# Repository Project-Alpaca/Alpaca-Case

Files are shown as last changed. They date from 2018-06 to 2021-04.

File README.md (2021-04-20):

# Alpaca-Case

Laser cut case for Alpaca.

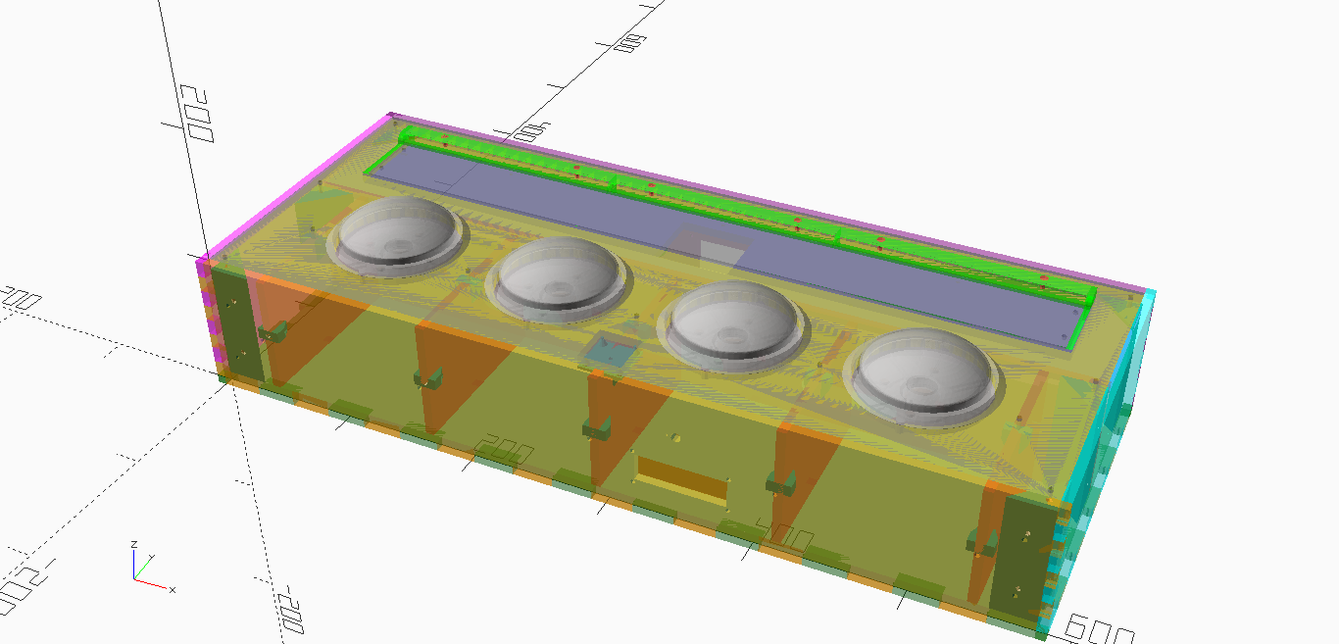
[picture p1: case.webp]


## Usage

- Don't forget to checkout all submodules by using `git submodule update --init --recursive`.
- Export the cutting (set `ENGRAVE=false`) and engraving (set `ENGRAVE=true`) profiles as DXF (via Customizer GUI or command line).
- Cut one sheet using the exported **cutting** profile.
- Engrave the same sheet using the exported **engraving** profile (beware of the alignment).
- Repeat the process using required materials until done.
- Print out all additional required parts in `models.scad` using a 3D printer.

### Customizer

The OpenSCAD Customizer is used in this project as a quick, non-invasive way to preview the design (in both 2D profile and assembled 3D model) and to simplify the build process. See the description fields in Customizer regarding to the usage of each options.

### laserscad

Make sure Python 3.9 and pipenv are installed.

After checkout or update, run

```sh
PIPENV_PIPFILE=ext/laserscad-alt/Pipfile pipenv install
```

To use laserscad support, run

```sh
PIPENV_PIPFILE=ext/laserscad-alt/Pipfile pipenv run python ext/laserscad-alt/lscad.py cut case.scad <page_width>x<page_height> -D '{"SHEET": "lscad", "PREVIEW_3D": false}'
```

(Parameters for HSI and/or LKP-Assy can be added by specifing extra parameters in the JSON object. e.g. `'{"SHEET": "lscad", "PREVIEW_3D": false, "LKP_PCB_TOTAL_LENGTH": 517, "HSI_DEPTH": 4.2}'`.)

Replace `cut` with `engrave` to generate engrave data. (WIP)

To use preview, run

```sh
PIPENV_PIPFILE=ext/laserscad-alt/Pipfile pipenv run python ext/laserscad-alt/lscad.py preview case.scad <page_width>x<page_height> -D '{"SHEET": "lscad", "PREVIEW_3D": false}'
```

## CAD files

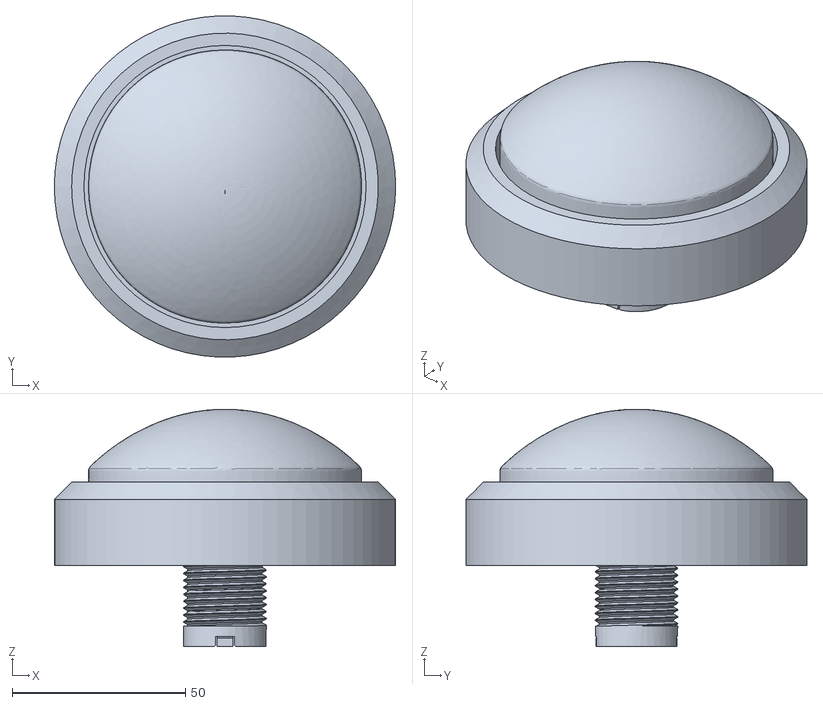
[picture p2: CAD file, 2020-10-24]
ext/adafruit-1185.stl
98.5 x 98.4 x 68.5

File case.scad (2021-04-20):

include <ext/lasercut/lasercut.scad>
include <ext/laserscad/dist/laserscad.scad>
include <footprints.scad>
use <ext/LKP-Assy/lkp-assy-ex.scad>
use <imperial.scad>
use <models.scad>

/* [Viewer Options] */
// Set this to true to get a 3D preview of the assembled controller
PREVIEW_3D = true;
_PREVIEW = $preview == undef || $preview == true ? PREVIEW_3D : false;
$fn = _PREVIEW ? undef : 48;

// Set this to true when PREVIEW_3D=false generates layer for laser engraving (mainly for position of screw holes so they can be drilled later)
ENGRAVE = false;

// box1, box2, box3 are intended to be cut from plywood, panel1 is intended to be cut from acrylic. lscad enables auto layout with laserscad. (currently requires our fork of laserscad with our custom layout script. See https://github.com/mbugert/laserscad/issues/4)
SHEET = "box1"; // [box1, box2, box3, panel1, lscad]
// Output drill layer on cut layer for direct cutting or engrave (eng) layer so that they can be drilled later.
DRILL_AS = "cut"; // [eng, cut]

// Size of panel sheet and box sheets (for reference only)
SHEET_PANEL = [in(24), in(18)];
SHEET_BOX = [in(24), in(16)];

/* [Preview Visibility] */
// Sets visibility of objects in preview

// Front
PREVIEW_FRONT_WALL = true;
// Back
PREVIEW_BACK_WALL = true;
// Left
PREVIEW_LEFT_WALL = true;
// Right
PREVIEW_RIGHT_WALL = true;
// Top cover
PREVIEW_TOP_COVER = true;
// Top panel
PREVIEW_TOP_PANEL = true;
// Bottom
PREVIEW_BOTTOM = true;
// Mounting brackets
PREVIEW_MOUNTING = true;
// Supports
PREVIEW_SUPPORT = true;
// LKP platform
PREVIEW_LKP_PLATFORM = true;
// LKP
PREVIEW_LKP = true;
// Button preview
PREVIEW_BUTTONS = true;

/* [Hidden] */

// Dimension settings

// Thickness of sheets
BOX_THICKNESS = in(1/4);
PANEL_THICKNESS = mil(80);

// Size of the inner box (without accounting controller panel)
BOX_SIZE = [580, 225, 95];
PANEL_SIZE_REF = [635, 225];

// Size of the outer edge
OUTER_SIZE = [
    BOX_SIZE.x + 2*BOX_THICKNESS,
    BOX_SIZE.y + 2*BOX_THICKNESS,
    // no tabs for z axis
    BOX_SIZE.z + BOX_THICKNESS
];
// Size of the inner box (minus controller panel thickness)
INNER_SIZE = [
    BOX_SIZE.x,
    BOX_SIZE.y,
    BOX_SIZE.z - BOX_THICKNESS - PANEL_THICKNESS
];

FINGER_COUNT = [10, 5, 4];

BUTTON_DIST = 125;
BUTTON_OFFSET_REF = [130, 75];
BUTTON_OFFSET = [
    BUTTON_OFFSET_REF.x - ((PANEL_SIZE_REF.x - BOX_SIZE.x) / 2),
    BUTTON_OFFSET_REF.y - ((PANEL_SIZE_REF.y - BOX_SIZE.y) / 2),
];
BUTTON_R_WITH_NOTCH = (ARCADE_BUTTON_100MM_HOLE_DIA + ARCADE_BUTTON_100MM_NOTCH_DIA) / 2;
SLIDER_SIZE_REF = [500, 40];
// Bottom of the slider, starts from the center of the buttons.
SLIDER_BOTTOM_Y = 75;
// Center of the slider, starts from the center of the buttons.
SLIDER_OFFSET_REF = [1.5*BUTTON_DIST, SLIDER_BOTTOM_Y + SLIDER_SIZE_REF.y/2];
// Button sits at zero. Therefore teh gap between slider and button (hole) would be (the slider bottom offset - the button radius with notch)
SLIDER_BUTTON_GAP_CENTER = SLIDER_BOTTOM_Y - ((SLIDER_BOTTOM_Y - BUTTON_R_WITH_NOTCH) / 2) + BUTTON_OFFSET.y;
BUTTON_OFFSET_BACKOFF = BUTTON_R_WITH_NOTCH + BUTTON_OFFSET.y + BOX_THICKNESS / 2 + 3;
LKP_PLATFORM_OFFSET = [0, BUTTON_OFFSET_BACKOFF + BOX_THICKNESS / 2];
SUPPORT_CORNER_OFFSET_Y = BUTTON_OFFSET_BACKOFF - BOX_THICKNESS/2;

// Center of the slider, starts from the bottom left of slider platform.
SLIDER_OFFSET_PLATFORM = SLIDER_OFFSET_REF + BUTTON_OFFSET - LKP_PLATFORM_OFFSET;

//SOFTPOT_WIDTH = 20;
//SOFTPOT_DEADZONE_WIDTH = 6;

// Internal use only. Do not change.

EPSILON = .1;

// Automatically generated dimension parameters
_box_side_fb_idim = [BOX_SIZE.x, BOX_SIZE.z];
_box_side_lr_idim = [BOX_SIZE.z, BOX_SIZE.y];
_box_tb_idim = [BOX_SIZE.x, BOX_SIZE.y];
_box_side_f_idim = _box_side_fb_idim;
_box_side_b_idim = _box_side_fb_idim;
_box_bottom_idim = _box_tb_idim;
_box_top_idim = _box_tb_idim;
_box_support_v_button_idim = [INNER_SIZE.z, BUTTON_OFFSET_BACKOFF - BOX_THICKNESS / 2];
_box_support_h_idim = [INNER_SIZE.x, INNER_SIZE.z];
_box_lkp_platform_idim = [INNER_SIZE.x, INNER_SIZE.y - LKP_PLATFORM_OFFSET.y];
_box_support_v_slider_idim = [BOX_SIZE.z-PANEL_THICKNESS+lkp_get_assy_zoffset()-BOX_THICKNESS, _box_lkp_platform_idim.y];


function account_for_fingers(dim, tb, lr) = [
    dim.x + BOX_THICKNESS * lr,
    dim.y + BOX_THICKNESS * tb,
];

_box_side_fb_xdim = account_for_fingers(_box_side_fb_idim, 1, 2);
_box_side_lr_xdim = account_for_fingers(_box_side_lr_idim, 2, 1);
_box_top_xdim = _box_top_idim;
_box_bottom_xdim = account_for_fingers(_box_bottom_idim, 2, 2);

// 1 group of fingers on the bottom
_box_support_h_xdim = account_for_fingers(_box_support_h_idim, 1, 0);
// 1 group of fingers on the vertical support and 1 group on the bottom
_box_support_v_button_xdim = account_for_fingers(_box_support_v_button_idim, 1, 1);
// 1 group of fingers on the vertical support and 1 group on the bottom
_box_support_v_slider_xdim = account_for_fingers(_box_support_v_slider_idim, 1, 1);
_box_lkp_platform_xdim = _box_lkp_platform_idim;

// Accounting for the thickness for lasercut boards
function as_lcb_center(pos) = pos - BOX_THICKNESS/2;

// Button gap center (-1: Before first button, 0: Gap center between the first and the second button)
function button_gap_center(pos) = BUTTON_DIST * (0.5+pos);

module extrude_box() {
    linear_extrude(BOX_THICKNESS) children();
}

module extrude_panel() {
    linear_extrude(PANEL_THICKNESS) children();
}

// Align box object's outer perimeter to the axis origin
module box_align_to_op(fingered_x=true, fingered_y=true) {
    translate([
        fingered_x ? BOX_THICKNESS : 0,
        fingered_y ? BOX_THICKNESS : 0,
    ]) children();
}

function support_index(i) = BUTTON_OFFSET.x+as_lcb_center(button_gap_center(i-1)+BOX_THICKNESS/2);

module copy_to_support_center(x_only=false) {
    for (i=[0:4]) {
        translate([support_index(i), 0, x_only ? 0 : BOX_THICKNESS]) children();
    }
}

module copy_to_support_center_no_oled(x_only=false) {
    for (i=[0, 1, 3, 4]) {
        translate([support_index(i), 0, x_only ? 0 : BOX_THICKNESS]) children();
    }
}

module move_to_support_center_oled(x_only=false) {
    translate([support_index(2), 0, x_only ? 0 : BOX_THICKNESS]) children();
}

module copy_to_slider_support_center(x_only=false) {
    for (i=[0:3]) {
        translate([support_index(i+0.5), 0, x_only ? 0 : BOX_THICKNESS]) children();
    }
}

module extrude_box_cutout() {
    translate([0, 0, -EPSILON])
    linear_extrude(BOX_THICKNESS+2*EPSILON)
        children();
}

module extrude_panel_cutout() {
    translate([0, 0, -EPSILON])
    linear_extrude(PANEL_THICKNESS+2*EPSILON)
        children();
}

module from_button_origin() {
    translate(BUTTON_OFFSET) children();
}

module corner_screw_holes(x, y) {
    //translate([0, 0, 0]) circle(d=3.2);
    translate([x, 0, 0]) circle(d=3.2);
    translate([0, y, 0]) circle(d=3.2);
}

// Wrappers
module support_holder_w(profile="3d", align_y="c") {
    support_holder(thickness=BOX_THICKNESS, profile=profile, align_y=align_y);
}

module corner_support_w(profile="3d") {
    corner_support(inner_height=INNER_SIZE.z, profile=profile);
}

module oled_holder_w(profile="3d-assy") {
    oled_holder(thickness=BOX_THICKNESS, profile=profile);
}
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

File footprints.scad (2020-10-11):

// Various footprints and their constants

include <imperial.scad>

/* [Hidden] */

// Constants. Do not edit.

// https://www.adafruit.com/product/1185#technical-details
ARCADE_BUTTON_100MM_DIA = 100;
ARCADE_BUTTON_100MM_HOLE_DIA = 88; // on drawing: 87.8
ARCADE_BUTTON_100MM_NOTCH_DIA = 6.2; // on drawing: 6.0

module footprint_arcade_button_100mm() {
    union() {
        _r = ARCADE_BUTTON_100MM_HOLE_DIA / 2;
        // main hole
        circle(d=ARCADE_BUTTON_100MM_HOLE_DIA);
        // notch
        translate([0, _r, 0]) {
            circle(d=ARCADE_BUTTON_100MM_NOTCH_DIA);
        }
        translate([0, -_r, 0]) {
            circle(d=ARCADE_BUTTON_100MM_NOTCH_DIA);
        }
    }
}

//module footprint_1602() {
//    square([80, 36], true);
//}

// Drill: invert=true, tail_cut=false
// Tail cut (difference): invert=true, holes=false
// TODO account for tail when positioning tail cut.
module footprint_softpot_mount(softpot_length=500, softpot_width=20, padding=20, invert=false, holes=true, tail_cut=true) {
    module _screw_holes() {
        offset_x = half_l + screw_hole_offset_from_pot;
        offset_y = half_w + screw_hole_offset_from_pot;
        translate([-offset_x, -offset_y]) circle(d=3.2);
        translate([offset_x, -offset_y]) circle(d=3.2);
        translate([-offset_x, offset_y]) circle(d=3.2);
        translate([offset_x, offset_y]) circle(d=3.2);
    }

    module _tail_cut() {
        offset_x = half_l + 5;
        translate([offset_x, 0]) square([3, 11], center=true);
    }

    screw_hole_offset_from_pot = padding / 4;
    half_l = softpot_length / 2;
    half_w = softpot_width / 2;

    if (!invert) {
        difference() {
            square([softpot_length+padding, softpot_width+padding], center=true);
            if (holes) _screw_holes();
            if (tail_cut) _tail_cut();
        }
    } else {
        %square([softpot_length+padding, softpot_width+padding], center=true);
        if (holes) _screw_holes();
        if (tail_cut) _tail_cut();
    }
    %square([softpot_length, softpot_width], center=true);
}

module footprint_1602() {
    %square([80, 36], center=true);
    square([73, 26], center=true);
}

module footprint_1602_eng() {
    %square([80, 36], center=true);
    translate([-80/2, -36/2, 0]) {
        translate([2.5, 2.5, 0]) circle(d=3.2);
        translate([80-2.5, 36-2.5, 0]) circle(d=3.2);
        translate([80-2.5, 2.5, 0]) circle(d=3.2);
        translate([2.5, 36-2.5, 0]) circle(d=3.2);
    }
}

module footprint_control() {
    %square([70, 30], center=true);
    square([63, 20], center=true);
}

module footprint_control_eng() {
    %square([70, 30], center=true);
    translate([-70/2, -30/2, 0]) {
        translate([2.5, 2.5]) circle(d=3.2);
        translate([70-2.5, 30-2.5, 0]) circle(d=3.2);
        translate([70-2.5, 2.5, 0]) circle(d=3.2);
        translate([2.5, 30-2.5, 0]) circle(d=3.2);
    }
}

module footprint_re() {
    %square([26, 19], center=true);
    translate([-3, 1.5]) {
        circle(d=7);
        translate([-6, 0]) {
            square([1, 2], center=true);
        }
    }
}

module footprint_re_eng() {
    %square([26, 19], center=true);
    //translate([-3, 1.5]) circle(d=7);
    translate([-26/2, -19/2, 0]) {
        translate([4.5, 2.5]) circle(d=3.2);
        translate([26-4.5, 2.5]) circle(d=3.2);
    }
}
module footprint_adafruit_908_ref() {
    translate([-14, 0]) hull() {
        circle(d=12);
        translate([28, 0]) circle(d=12);
    }
}

module footprint_adafruit_908() {
    %footprint_adafruit_908_ref();
    square([14.5, 7], center=true);
}

module footprint_adafruit_908_eng() {
    %footprint_adafruit_908_ref();
    translate([15, 0]) circle(d=in(7/64));
    translate([-15, 0]) circle(d=in(7/64));
}

module footprint_adafruit_3258_ref() {
    union() {
        translate([-8.5, 0]) hull() {
            circle(d=8);
            translate([17, 0]) circle(d=8);
        }
        minkowski() {
            square([12-4, 10-4], center=true);
            circle(r=2);
        }
    }
}

module footprint_adafruit_3258() {
    %footprint_adafruit_3258_ref();
    square([9, 4.5], center=true);
}

module footprint_adafruit_3258_eng() {
    %footprint_adafruit_3258_ref();
    translate([-9, 0]) circle(d=in(7/64));
    translate([9, 0]) circle(d=in(7/64));
}
module footprint_tensility_54_00063() {
    circle(d=11);
}

module footprint_back_panel() {
    // Thickness should not exceed 2.5mm otherwise micro USB plug will not
    // fit
    %square([60,40], center=true);
    difference() {
        square([75,50], center=true);
        translate([20, 0, 0]) rotate([0, 0, 90]) footprint_adafruit_3258();
        rotate([0, 0, 90]) footprint_adafruit_908();
        translate([-20, 0, 0]) rotate([0, 0, 90]) footprint_tensility_54_00063();
    }
}

module footprint_back_panel_eng() {
    translate([20, 0, 0]) rotate([0, 0, 90]) footprint_adafruit_3258_eng();
    rotate([0, 0, 90]) footprint_adafruit_908_eng();
    translate([34.5, 22]) circle(d=3.2);
    translate([-34.5, 22]) circle(d=3.2);
    translate([34.5, -22]) circle(d=3.2);
    translate([-34.5, -22]) circle(d=3.2);
}

module footprint_back_panel_cutout() {
    square([60,40], center=true);
}

module footprint_back_panel_cutout_eng() {
    translate([34.5, 22]) circle(d=3.2);
    translate([-34.5, 22]) circle(d=3.2);
    translate([34.5, -22]) circle(d=3.2);
    translate([-34.5, -22]) circle(d=3.2);
}

module footprint_tp_contact_notch() {
    module side_notch() {
        union() {
            square([4, 14], center=true);
            translate([0, 5-4/2]) square([5+4/2, 4], center=false);
            translate([0, -5-4/2]) square([5+4/2, 4], center=false);
        }
    }

    translate([-50, 0]) side_notch();
    translate([50, 0]) mirror([1, 0]) side_notch();

    translate([-25, 5]) square([15, 4], center=true);
    translate([25, -5]) square([15, 4], center=true);
    translate([-25, -5]) square([15, 4], center=true);
    translate([25, 5]) square([15, 4], center=true);
    translate([0, 5]) square([10, 4], center=true);
}

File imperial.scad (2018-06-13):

IN_TO_MM = 25.4;

function in(length) = length * IN_TO_MM;
function mil(length) = in(length / 1000);
function thou(length) = mil(length);
function ft(length) = in(length)/12;

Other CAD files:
models.scad

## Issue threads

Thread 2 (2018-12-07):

SoftPot is off-center

dogtopus, 2018-12-07:
Currently the SoftPot is positioned without the tail in mind and it is off-center by a few centimeters.

dogtopus, 2020-10-24:
No longer relavent.

Closed 2020-10-24.

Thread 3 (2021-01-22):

Things to do before v2 release

dogtopus, 2021-01-22:
- [ ] Add LKP screw hole drill profile to slider platform.
- [ ] Add another pair of corner supports to horizon pivot on the button side
- [ ] Relocate ports and display

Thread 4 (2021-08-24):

Rotary encoder hole is too deep

dogtopus, 2021-08-24:
The rotary encoder hole is too deep for most generic rotary encoders (even the 7mm ones). Should probably move it to a 3D-printed panel instead. Maybe integrate it with the front Select/Home/Start panel.

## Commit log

2018-06-26 Almost done
    [case.scad, footprints.scad, models.scad]
2018-06-27 Finally done :P
    [case.scad, models.scad]
2018-07-05 Add bottom screw holes
    [case.scad]
2018-07-05 Fix softpot mount preview
    [case.scad]
2018-08-23 Workaround rounding issues by run projection on lasercut object before other modifiers
    [case.scad]
2018-08-23 Model selector
    [models.scad]
2019-01-16 Reduce height
    [case.scad]
2019-02-08 Remove center parameter from circle() as it does nothing
    [case.scad, footprints.scad, models.scad]
2019-02-08 Use the "new" $preview variable to ensure that preview shape only exists in preview window
    [case.scad]
2019-02-25 Temporarily switch to private repo for unmerged fixes
2019-02-25 Use Customizer as a configurator for preview.
    The heavy use of in() and mil() macros makes some options not displayable.
    This is expected and unlikely to change in the future.
    [case.scad]
2019-02-25 Use .{x,y,z} accessor instead of rolling out our own.
    [case.scad]
2019-03-02 Switch lasercut module back to upstream
2019-06-18 Use discrete variables for preview visibility options
    [case.scad, footprints.scad, models.scad]
2019-06-18 Reorder preview drawing sequence to take some advantage from
    pseudo-transparency
    [case.scad]
2019-06-18 Make the cutout slightly taller to prevent preview glitch
    [case.scad]
2019-06-18 Remove top alignment tabs on the pivot
    [case.scad]
2019-06-19 Major refactor and some v2 work
    [case.scad, footprints.scad]
2019-06-19 Box top is now a native 2D object
    [case.scad]
2019-06-22 Avoid copy-pasting linear_extrude parameters everywhere by defining extrude_*(_cutout) modules
    [case.scad]
2019-06-24 Vertical pivot placeholders
    [case.scad]
2019-06-24 Increase EPSILON again to prevent Z-fighting on zoomed-out situation
    [case.scad]
2020-09-18 Introduce _<part>_idim variable. Prepare for use with laserscad.
    idim standands for internal dimension (the dimension lasercut library works on).
    Later there will also be xdim which is the dimension of the actual parts on the
    sheet. This accounts for the extra space used by the joint fingers, etc. The
    laserscad script requires this to determine the bounding box for each
    component. Also the naming scheme can (hopefully) reduce potential confusion
    that may be caused by BOX_SIZE since BOX_SIZE mapping is IMO not as
    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
    [case.scad]
2020-10-10 Partially integrate LKP into the design
    [case.scad]
2020-10-10 Use use statement when possible
    [case.scad]
2020-10-11 Change the backoff strategy to button edge+offset to allow more headroom to LKP
    [case.scad]
2020-10-11 Add preview for LKP platform. Fix backoff offset
    [case.scad]
2020-10-11 Fix preview translarency for LKP platform. Start working on new mounting system.
    [case.scad, footprints.scad, models.scad]
2020-10-11 Reduce tolerance for the button notches
    [footprints.scad]
2020-10-12 Fix copypasta fails
    [case.scad]
2020-10-12 More work on laserscad support
    [case.scad]
2020-10-13 Switch to custom fork
2020-10-13 Fix box_side_lr offset
    [case.scad]
2020-10-13 Integrate laserscad-alt
2020-10-13 Separate drill profiles from engrave layer
    [case.scad]
2020-10-13 Implement direct cutting for drill layer.
    [case.scad]
2020-10-13 Use extrude_box_cutout for drill layers
    [case.scad]
2020-10-18 New mounting system modeling.
    [case.scad, models.scad]
2020-10-20 Add tabs to pivot_v_button_*. Update deps.
    [case.scad, models.scad]
2020-10-23 Add drill/cut profiles for pivot holder.
    Other changes:
    - Fix a positioning issue when using laserscad.
    - Fix bottom wall thickness of pivot holder (0.6 -> 2).
    - General code cleanup.
    [case.scad, models.scad]
2020-10-23 Add panel/box wall screw holes for pivot holder
    [case.scad, models.scad]
2020-10-24 Add button preview
    [adafruit-1185.stl, case.scad, models.scad]
2020-10-24 More holes for mounting and tabs
    [case.scad, models.scad]
2020-10-24 Change pivot_index definition to make it less confusing
    [case.scad]
2021-01-20 Add corner support cutouts to LKP platform
    [case.scad, models.scad]
2021-01-20 Update the notice on laserscad
    [case.scad]
2021-01-20 Update laserscad-alt
2021-01-21 Add slider pivots
    [case.scad]
2021-01-22 Add tab holes for slider pivots
    [case.scad]
2021-01-22 Add drill profiles for LKP platform pivot holders
    [case.scad, models.scad]
2021-01-23 Add LKP screw hole drill and cut profile to slider platform.
    [case.scad]
2021-01-30 Add corners for joints between horizontal pivot and LR walls
    [case.scad]
2021-01-30 Add screw holes for pivot corners
    [case.scad]
2021-02-02 Add LKP LED cable holes to slider platform.
    [case.scad]
2021-02-04 Relocate ports
    [case.scad]
2021-02-12 Remove LCD hole
    [case.scad]
2021-03-06 Add OLED module holder
    [models.scad]
2021-03-06 Add cutout (under panel) for OLED screen
    [models.scad]
2021-03-06 Add cutouts for OLED holder
    [case.scad, models.scad]
2021-03-07 Add cable holes on slider pivot and horizontal pivot.
    [case.scad, models.scad]
2021-03-14 Remove PC from working material for panel since the current design is not router-safe out-of-the-box.
    [case.scad]
2021-04-20 Replace "pivot" with "support".
    In Alpaca v1 there is only 1 support piece that sits right at the middle of
    the controller X axis. It was thus called a "pivot". However in Alpaca v2 the
    support structure is a lot more complicated. It has support pieces
    distributed at various locations rather than just at the middle of the X axis.
    So "pivot" no longer makes any sense and just call them "supports" would be
    better.
    [case.scad, models.scad]
